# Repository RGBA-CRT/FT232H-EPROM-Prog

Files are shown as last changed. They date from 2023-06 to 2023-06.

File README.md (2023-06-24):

# FT232H-EPROM-Prog
+ USB 27C322 EPROM Programmer with FT232H.
+ software and hardware.
+ only supports 27C322.
+ *THIS REPOSITORY IS FOR EXPERIMENTAL PURPOSES.* all function is work in progress.
+ このリポジトリの内容はすべて個人的な実験目的です。コードや回路を読める方以外は利用をお勧めできません。





# About 2017
- FT232Hを使ったEPROMライタ(プログラマ)
- 数点の部品で作れるので、高価なEPROMライタがいらない
- EEPROM, FlashMemoryには**未対応**
- シリアルEEPROM, PICには非対応
- 27C322と27C160で動作確認
- **現在テストプログラムの段階**
- ビルドには[こちらの[AB-FT232HLib]](https://github.com/RGBA-CRT/AB-FT232HLib)が必要

## 回路
pcbディレクトリを見てください。
[回路図PDF](pcb/kairo_v2.1b.pdf)
sch

## 関連リポジトリ
+ 27C322 x2基板
  + https://github.com/RGBA-CRT/RGBA_CRT_ROM_BOARD
+ FT232H制御ライブラリ for ActiveBasic
   + https://github.com/RGBA-CRT/AB-FT232HLib

----
Programmed by RGBA_CRT 2017-2023  
Project url: https://github.com/RGBA-CRT/FT232H-EPROM-Prog

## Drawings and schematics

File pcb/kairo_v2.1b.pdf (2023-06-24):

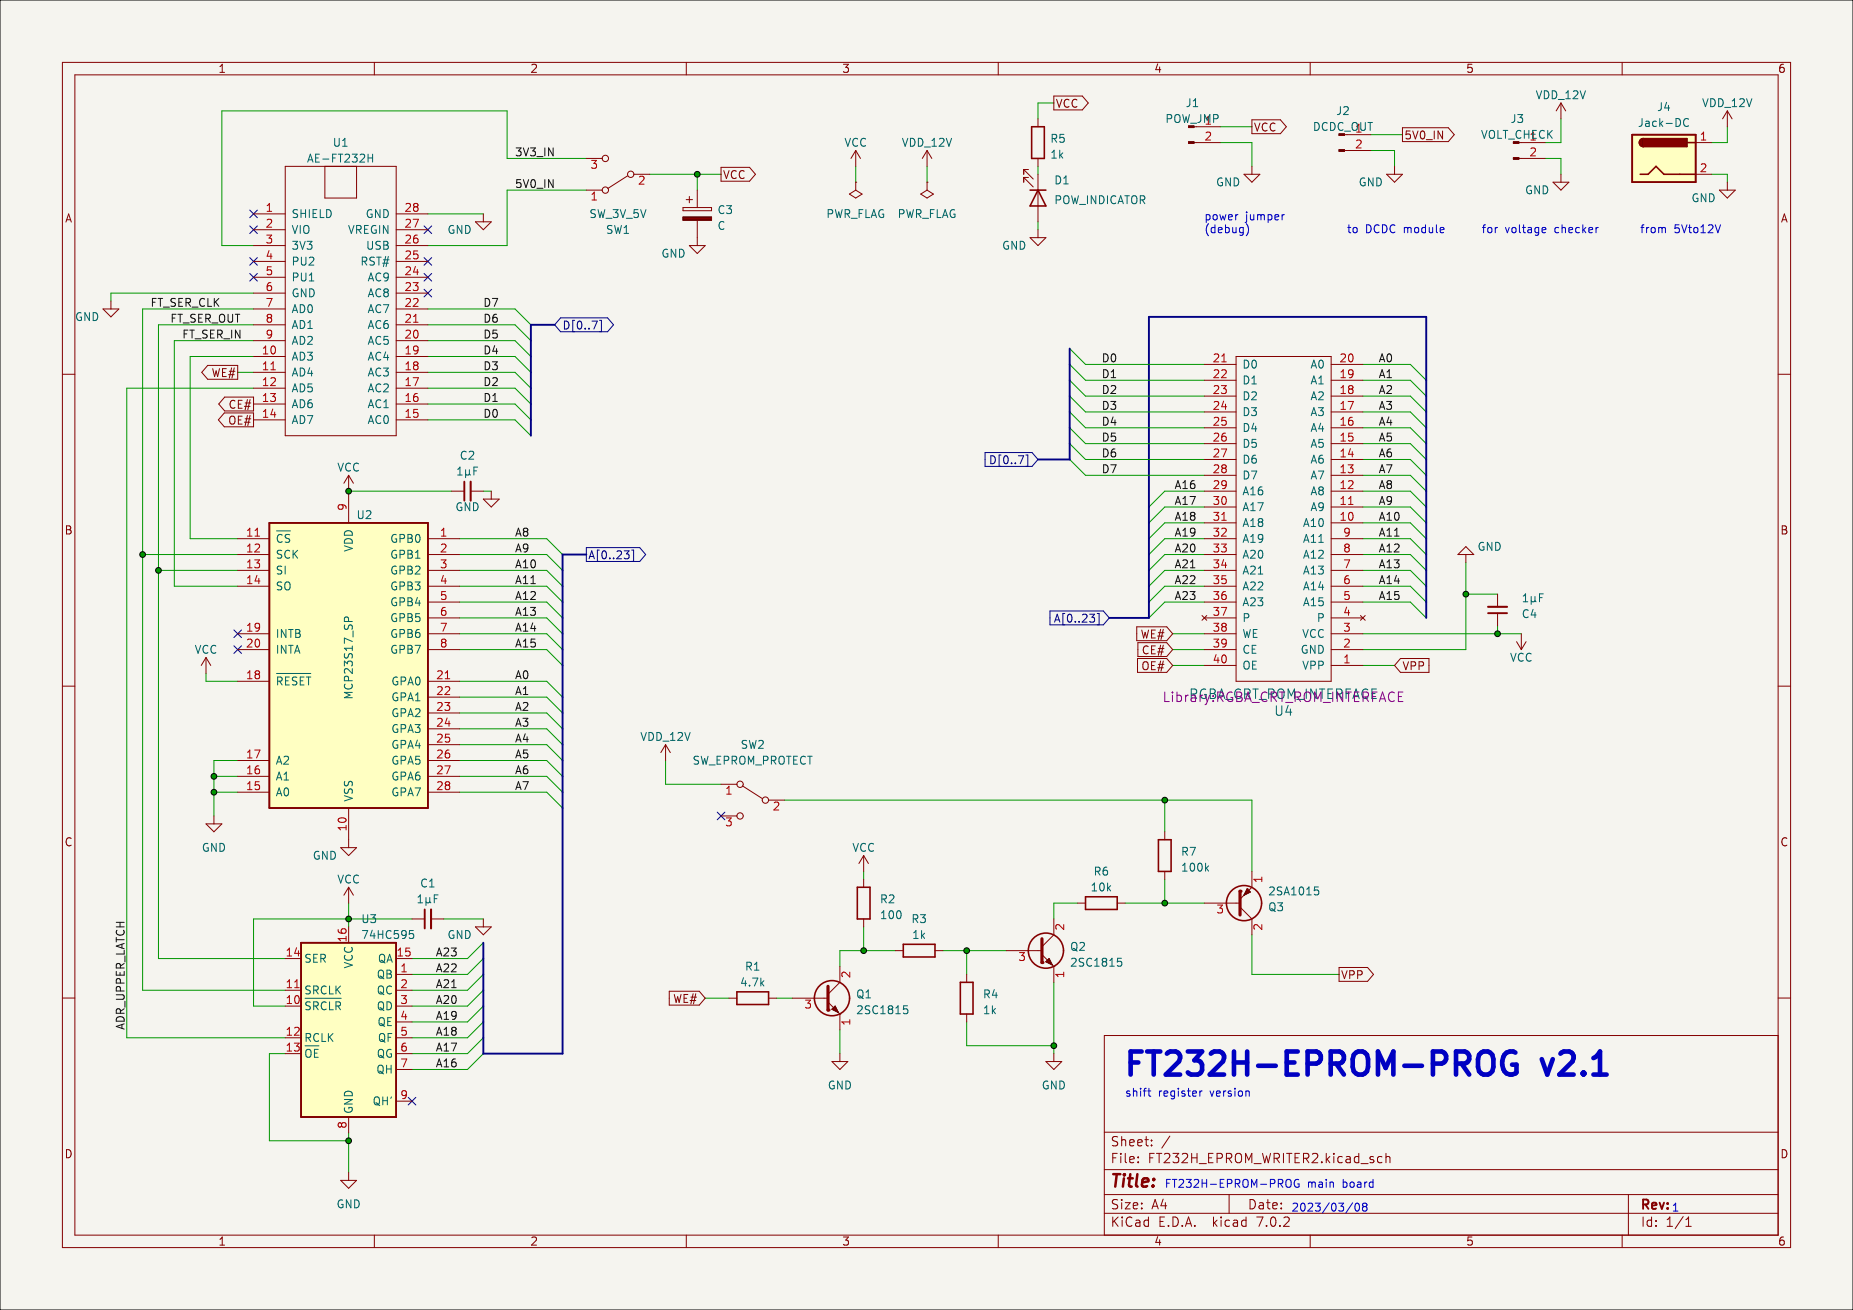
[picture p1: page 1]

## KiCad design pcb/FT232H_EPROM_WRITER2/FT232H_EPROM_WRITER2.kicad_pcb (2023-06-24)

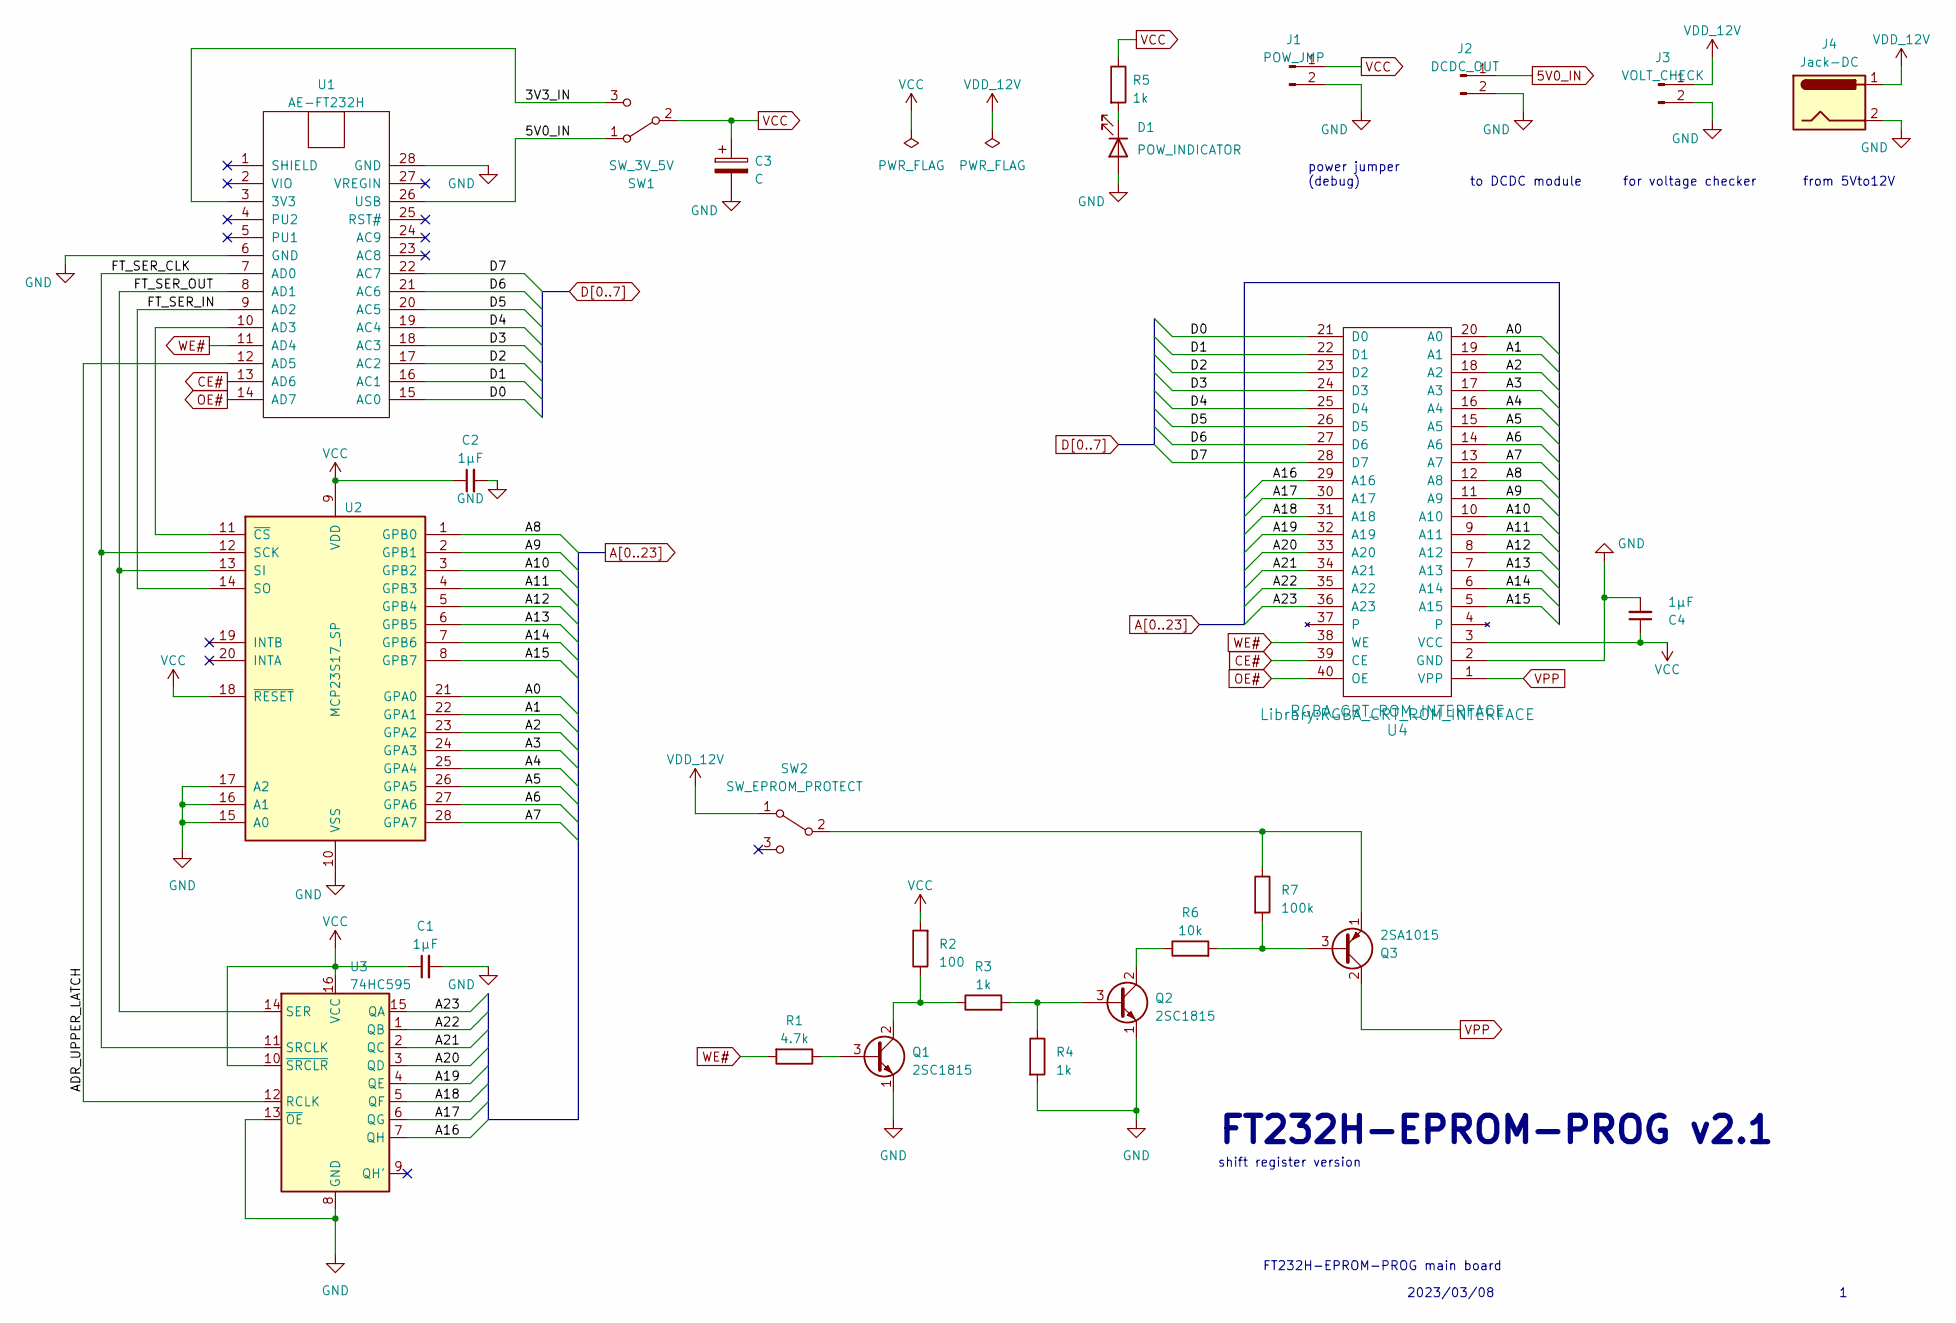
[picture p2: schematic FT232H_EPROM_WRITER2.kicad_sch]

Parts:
C1: 1μF; C_Disc_D4.3mm_W1.9mm_P5.00mm
C2, C4: 1μF; C_Disc_D3.4mm_W2.1mm_P2.50mm
C3: C; C_Radial_D5.0mm_H5.0mm_P2.00mm
D1: POW_INDICATOR; LED_D2.0mm_W4.0mm_H2.8mm_FlatTop
J1: POW_JMP; PinHeader_2x01_P2.54mm_Vertical
J2: DCDC_OUT; PinHeader_2x01_P2.54mm_Vertical
J3: VOLT_CHECK; PinHeader_2x01_P2.54mm_Vertical
J4: Jack-DC; PinHeader_2x01_P2.54mm_Vertical
Q1, Q2: 2SC1815; TO-92_Inline_Wide
Q3: 2SA1015; TO-92_Inline_Wide
R1: 4.7k; R_Axial_DIN0204_L3.6mm_D1.6mm_P2.54mm_Vertical
R2: 100; R_Axial_DIN0204_L3.6mm_D1.6mm_P2.54mm_Vertical
R3, R4, R5: 1k; R_Axial_DIN0204_L3.6mm_D1.6mm_P2.54mm_Vertical
R6: 10k; R_Axial_DIN0204_L3.6mm_D1.6mm_P2.54mm_Vertical
R7: 100k; R_Axial_DIN0204_L3.6mm_D1.6mm_P2.54mm_Vertical
SW1: SW_3V_5V; PinHeader_1x03_P2.54mm_Vertical
SW2: SW_EPROM_PROTECT; PinHeader_1x03_P2.54mm_Vertical
U1: AE-FT232H; DIP-28_W15.24mm
U2: MCP23S17_SP; DIP-28_W7.62mm
U3: 74HC595; DIP-16_W7.62mm
U4: RGBA_CRT_ROM_INTERFACE

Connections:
5V0_IN: J2.1, SW1.1 (A), U1.26 (USB)
/3V3_IN: SW1.3 (C), U1.3 (3V3)
/ADR_UPPER_LATCH: U1.12 (AD5), U3.12 (RCLK)
/FT_SER_CLK: U1.7 (AD0), U2.12 (SCK), U3.11 (SRCLK)
/FT_SER_IN: U1.9 (AD2), U2.14 (SO)
/FT_SER_OUT: U1.8 (AD1), U2.13 (SI), U3.14 (SER)
A0: U2.21 (GPA0), U4.20 (A0)
A1: U2.22 (GPA1), U4.19 (A1)
A2: U2.23 (GPA2), U4.18 (A2)
A3: U2.24 (GPA3), U4.17 (A3)
A4: U2.25 (GPA4), U4.16 (A4)
A5: U2.26 (GPA5), U4.15 (A5)
A6: U2.27 (GPA6), U4.14 (A6)
A7: U2.28 (GPA7), U4.13 (A7)
A8: U2.1 (GPB0), U4.12 (A8)
A9: U2.2 (GPB1), U4.11 (A9)
A10: U2.3 (GPB2), U4.10 (A10)
A11: U2.4 (GPB3), U4.9 (A11)
A12: U2.5 (GPB4), U4.8 (A12)
A13: U2.6 (GPB5), U4.7 (A13)
A14: U2.7 (GPB6), U4.6 (A14)
A15: U2.8 (GPB7), U4.5 (A15)
A16: U3.7 (QH), U4.29 (A16)
A17: U3.6 (QG), U4.30 (A17)
A18: U3.5 (QF), U4.31 (A18)
A19: U3.4 (QE), U4.32 (A19)
A20: U3.3 (QD), U4.33 (A20)
A21: U3.2 (QC), U4.34 (A21)
A22: U3.1 (QB), U4.35 (A22)
A23: U3.15 (QA), U4.36 (A23)
CE#: U1.13 (AD6), U4.39 (CE)
D0: U1.15 (AC0), U4.21 (D0)
D1: U1.16 (AC1), U4.22 (D1)
D2: U1.17 (AC2), U4.23 (D2)
D3: U1.18 (AC3), U4.24 (D3)
D4: U1.19 (AC4), U4.25 (D4)
D5: U1.20 (AC5), U4.26 (D5)
D6: U1.21 (AC6), U4.27 (D6)
D7: U1.22 (AC7), U4.28 (D7)
GND: C1.2, C2.2, C3.2, C4.2, D1.2 (A), J1.2, J2.2, J3.2, J4.2, Q1.1 (E), Q2.1 (E), R4.2, U1.6 (GND), U1.28 (GND), U2.10 (VSS), U2.15 (A0), U2.16 (A1), U2.17 (A2), U3.8 (GND), U3.13 (~OE), U4.2 (GND)
unnamed: D1.1 (K), R5.2
unnamed: Q1.3 (B), R1.1
unnamed: Q1.2 (C), R2.1, R3.1
unnamed: Q2.3 (B), R3.2, R4.1
unnamed: Q2.2 (C), R6.1
unnamed: Q3.3 (B), R6.2, R7.2
unnamed: Q3.1 (E), R7.1, SW2.2 (B)
unnamed: U1.10 (AD3), U2.11 (~CS)
OE#: U1.14 (AD7), U4.40 (OE)
VCC: C1.1, C2.1, C3.1, C4.1, J1.1, R2.2, R5.1, SW1.2 (B), U2.9 (VDD), U2.18 (~RESET), U3.10 (~SRCLR), U3.16 (VCC), U4.3 (VCC)
VDDA: J3.1, J4.1, SW2.1 (A)
VPP: Q3.2 (C), U4.1 (VPP)
WE#: R1.2, U1.11 (AD4), U4.38 (WE)

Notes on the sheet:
FT232H-EPROM-PROG main board
to DCDC module
from 5Vto12V
FT232H-EPROM-PROG v2.1
power jumper (debug)
shift register version
for voltage checker
2023/03/08

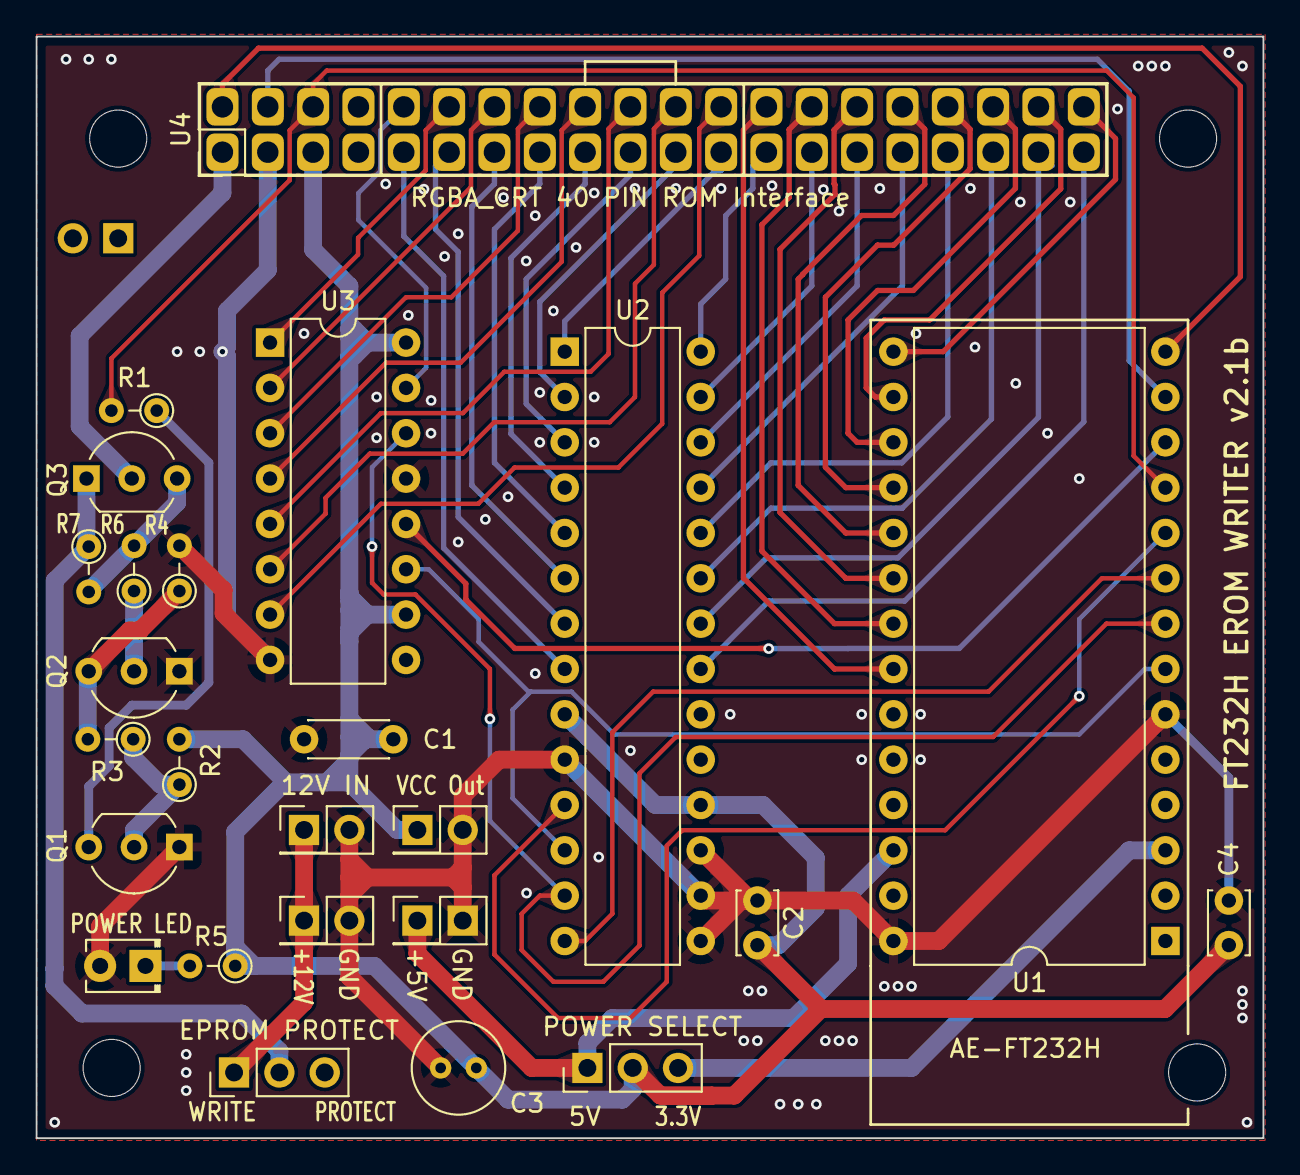
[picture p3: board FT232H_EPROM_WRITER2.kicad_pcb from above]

Board: 2 copper layers, 68.7 x 61.7 mm, 30 parts (1 on the bottom side), 53 nets.

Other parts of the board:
GND_PIN: PinHeader_1x02_P2.54mm_Vertical
MOUNT1, MOUNT1#2, MOUNT1#3, MOUNT1#4: MountingHole_3.2mm_M3

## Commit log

2017-07-27 "高速化"
2023-04-09 WIP: PCBv2
2023-06-19 Impl: PCBv2
2023-06-24 Add kicad files.
    [FT232H_EPROM_WRITER2.kicad_pcb, FT232H_EPROM_WRITER2.kicad_sch, FT232H_EPROM_WRITER2.sch]
